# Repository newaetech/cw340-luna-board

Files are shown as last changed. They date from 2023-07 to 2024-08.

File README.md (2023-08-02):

# CW340 Luna Baseboard

This repository contains the hardware documentation for the CW340 Luna Baseboard. This board supports multiple larger FPGA target boards.

### Status

The baseboard is now released. 

Latest (Revision 05) Known Issues:
* A production mod is applied to add a pull on the reset pins. This has been done on all shipped boards.

## CW341 Kintex Ultrascale KU095 Target

### Status

The board is now released.

## CW342 Kintex K410T Target

### Status

Early alpha has been built & tested.

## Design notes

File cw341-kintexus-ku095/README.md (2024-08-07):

# CW341 Luna Board (Kintex UltraScale Daughtercard)

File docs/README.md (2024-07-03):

# CW340 Luna Board (OpenTitan Baseboard)

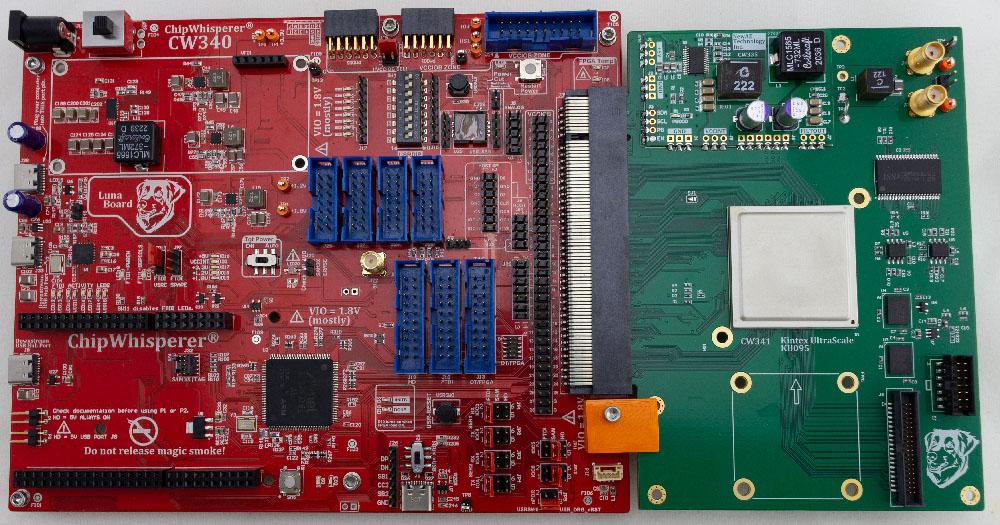
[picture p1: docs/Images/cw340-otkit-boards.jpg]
CW340 OTKIT Luna Board

The ChipWhisperer CW340 "Luna Board" is an advanced evaluation platform for FPGA-based security SoC, RoT, or HSM based designs. It is specifically designed to meet the needs of security evaluation purposes, while having the features you would expect in an easy-to-use FPGA development board.

The CW340 is designed specifically for working with the OpenTitan design, either in FPGA emulation or with a production silicon device.

!!! tip "Quick Reference to Schematics and More"
    For the schematic see [Schematic](#reference-material-schematics) section.
    For FPGA examples see [GITHub Repo](https://github.com/newaetech/cw340-luna-board).
	For PCB source files see [GITHub Repo](https://github.com/newaetech/cw340-luna-board)

This board includes a programmable microcontroller that communicates with the target FPGA, as well as a generic FTDI interface for serial & JTAg interface. The microcontroller is responsible for tasks including:

* Configuring/reconfiguring the FPGA using serial or SelectMAP.
* Monitor the FPGA temperature, controlling fans, shutting down power if entering over-temp situation.
* Adjusting the core voltage.
* Controlling the on-board PLL to set required clock frequency.
* Allowing power cycling of the FPGA target.
* Address/data bus which can be used as 30 computer-controller GPIO pins instead.
* Generic SPI interface.

In addition, the board includes several useful features for development of SoC like devices:

* 1x QSPI sockets - one with 1.8V fixed VCC, one with adjustable VCC.
* Standard JTAG headers that are compatible with most Arm & RISC-V debug probes.
* USB with PHY chip.
* PMOD headers
* Large card-edge connector for the FPGA submodule.

## CW341 Kintex UltraScale (OpenTitan Emulation) FPGA Board

The CW340 "OT KIT" edition includes the CW341 Kintex UltraScale FPGA board. This board has a separate
documentation page. Briefly, features of the CW341 include:

* SRAM and HyperRam for memory expansion.
* Simple PCB design makes it possible to build your own (especially useful if you have stock of the FPGAs).
* JTAG and expansion headers on-board.
* Separate VCC-INT power supply module to further simplify building your own board.

The FPGA board also contains multiple features specific for power analysis & fault injection testing:

* Multi-stage filtering of VCC-INT power supplies to reduce noise.
* On-board inductive "shunt" for power measurements.
* Bridgeable test points for performing other operations with VCC-INT supply.
* SMA connectors for voltage fault injection.
* Cross-flow fans allow access to die for EM probing or EMFI fault injection.
* BGA is mounted with open area to allow removal of heat spreader with minimal risk.

## Usage

### OpenTitan

If you want to use OpenTitan with the CW340, we recommend following their instructions at https://github.com/lowRISC/opentitan/blob/master/doc/getting_started/setup_fpga.md

### Custom BitStreams

If instead you want to build and develop your own bitstreams, you may find it more convenient to
use the ChipWhisperer Python API. Using the board in this way is very similar to using the
CW305 or CW310 boards:

```python
# program bitstream
import chipwhisperer as cw
target = cw.target(None, cw.targets.CW340, bsfile="/path/to/bitstream.bit", force=True)

# Set PLLs
target.pll.pll_enable_set(True)
target.pll.pll_outenable_set(False, 0)
target.pll.pll_outenable_set(True, 1)
target.pll.pll_outenable_set(False, 2)

# run at 10 MHz:
target.pll.pll_outfreq_set(10E6, 1)
```

### UART

The CW340 has two options for using UART: 2 FTDI UART channels, and a custom SAM3X microcontroller
driver with 2 channels. `lsusb` on Linux and Device Manager on Windows can be used to
figure out which serial ports are associated with which. The following image shows the two FTDI
channels on the top and the two SAM3X channels on the bottom:

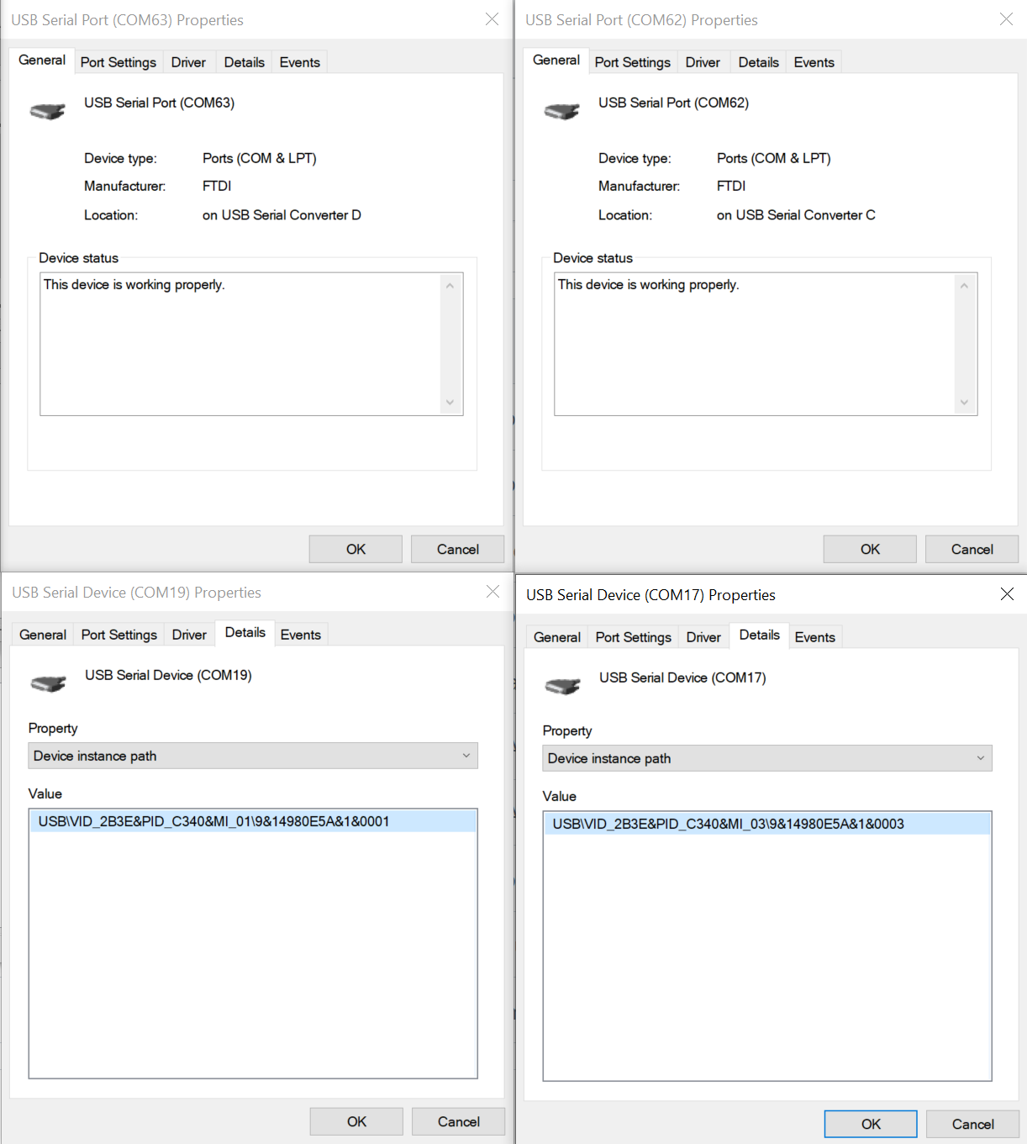
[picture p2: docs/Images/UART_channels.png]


The following is an output from `lsusb -tv`:

```
/:  Bus 03.Port 1: Dev 1, Class=root_hub, Driver=xhci_hcd/4p, 480M
    ID 1d6b:0002 Linux Foundation 2.0 root hub
    |__ Port 2: Dev 2, If 0, Class=Hub, Driver=hub/4p, 480M
        ID 2109:2813 VIA Labs, Inc. VL813 Hub
        |__ Port 2: Dev 4, If 0, Class=Hub, Driver=hub/4p, 480M
            ID 0424:2534 Microchip Technology, Inc. (formerly SMSC) 
            |__ Port 1: Dev 7, If 3, Class=Communications, Driver=cdc_acm, 480M
                ID 2b3e:c340 NewAE Technology Inc. 
            |__ Port 1: Dev 7, If 1, Class=Communications, Driver=cdc_acm, 480M
                ID 2b3e:c340 NewAE Technology Inc. 
            |__ Port 1: Dev 7, If 4, Class=CDC Data, Driver=cdc_acm, 480M
                ID 2b3e:c340 NewAE Technology Inc. 
            |__ Port 1: Dev 7, If 2, Class=CDC Data, Driver=cdc_acm, 480M
                ID 2b3e:c340 NewAE Technology Inc. 
            |__ Port 1: Dev 7, If 0, Class=Vendor Specific Class, Driver=, 480M
                ID 2b3e:c340 NewAE Technology Inc. 
            |__ Port 2: Dev 6, If 3, Class=Vendor Specific Class, Driver=ftdi_sio, 480M
                ID 0403:6011 Future Technology Devices International, Ltd FT4232H Quad HS USB-UART/FIFO IC
            |__ Port 2: Dev 6, If 1, Class=Vendor Specific Class, Driver=ftdi_sio, 480M
                ID 0403:6011 Future Technology Devices International, Ltd FT4232H Quad HS USB-UART/FIFO IC
            |__ Port 2: Dev 6, If 2, Class=Vendor Specific Class, Driver=ftdi_sio, 480M
                ID 0403:6011 Future Technology Devices International, Ltd FT4232H Quad HS USB-UART/FIFO IC
            |__ Port 2: Dev 6, If 0, Class=Vendor Specific Class, Driver=ftdi_sio, 480M
                ID 0403:6011 Future Technology Devices International, Ltd FT4232H Quad HS USB-UART/FIFO IC
```

#### Troubleshooting: /dev/ttyUSB* Not Showing Up

If the FTDI UART channels aren't showing up in Linux (usually `/dev/ttyUSB1-4`), the most likely cause is that the FTDI driver isn't being loaded.

Run the following command to install and load the driver:

```bash
sudo apt install linux-modules-extra-`uname -r` # install driver
sudo modprobe ftdi_sio # load driver
```

By default, this will only load the driver for this boot session, meaning if you restart, you'll need to rerun the `modprobe` command. To load
the FTDI driver on boot, append `ftdi_sio` to `/dev/modules`

### Jumpers

#### UART Jumpers (JP1-JP4)

The default UART IO pins for OpenTitan (OT_IOC3, OT_IOC4, OT_IOA0, and OT_IOA1) can be routed to the following locations:

1. Onboard FTDI UART chip
1. Onboard SAM3X microcontroller
1. Header pins (J18)

For most situations, we recommend routing to the FTDI UART pins.

Note that TX/RX are from the FPGA's perspective, so that things are sent to the FPGA on the RX line and sent from the FPGA on the TX line.

#### Other Jumpers

Most other jumpers on the CW340 will not need to be touched by the user. They do the following:

* JP5 routes the OpenTitan power on reset pin to either a switch (USRSW0) or J29
* JP6 routes 1.8V to User SPI 1
* JP7 has GPIOL0 and GPIOL1 of FTDI channel D
* JP8 has PLL_CLK2 and the /USB_CE signal
* JP9 can be used to set VCCIOB to either 1.2V, 1.8V, or 3.3V
* JP11 and JP12 set OT_IOC5 and OT_IOC8, respectively, to either FTDI control or SAM3X control
* JP13 sets the 1.8V supply for the FTDI chip to either come from the SAM 1.8V regulator, or from a separate regulator 

## Firmware Upgrade

If you need to upgrade the firmware on the SAM3X (control microcontroller), this is currently done through two steps:

1. Erase the SAM3X, causing it to enter bootloader mode.
2. Program the SAM3X with the new firmware.

See the following for details of these steps.

!!! tip "Automatic Bootloader"
    Our other devices have a simplified "automatic" bootloader programmer - currently the CW340 firmware isn't distributed with ChipWhisperer, so for now use the following manual method.

### Step 1: Erasing the SAM3X

This can be done in two ways. Via Python:

```
import chipwhisperer as cw
target = cw.target(None, cw.targets.CW340)
programmer = cw.SAMFWLoader(scope=target)
programmer.enter_bootloader(really_enter=True)
```

Alternative, short the jumper holes marked "ERASE" (J20) with a paperclip, tweezers, etc.

If this part is successful, the leds D23 and D9 will be dimly lit. The CW340 will then **re-enumerate as a serial port**.

### Step 2: Reprogramming the SAM3X

In the following step, you may need to add explicit permission for the bootloader serial port. This is a different USB interface than is normally used by the device.

Get the latest firmware from GIT, note that the file is stored as part of the CW340 repo:

```
wget https://github.com/newaetech/cw310-bergen-board/raw/main/microfw/CW310/src/CW340.bin
```

And then:

```python
import chipwhisperer as cw
programmer = cw.SAMFWLoader(scope=None)
programmer.program('COM3', 'CW340.bin')
```

If this is successful you will see something like:

```
Opening firmware...
Opened!
Connecting...
b'\n\r'
Connected!
Erasing...
Erased!
Programming file CW340.bin...
Programmed!
Verifying...
Verify OK!
Bootloader disabled. Please power cycle device.
```

Press the "USB RST" button (SW5) on the board or power cycle it.

!!! tip "No Touch Bootloader"
    The latest git will support an automatic bootloader which does not require you to power cycle or touch the physical board. If your board automatically re-enumerates, you do not need to do the "USB RST" command.

## Reference Material (Schematics)

* [View schematics online](https://github.com/newaetech/cw340-luna-board/blob/main/docs/NPCA-CW340-LUNABOARD-05.PDF)
* [Download PDF of Schematics](https://github.com/newaetech/cw340-luna-board/raw/main/docs/NPCA-CW340-LUNABOARD-05.PDF)

## Errata

### PLL

PLLs 1 and 2 are swapped from the CW305. The ChipWhisperer Python library swaps them back such that setting
PLL1 sets PLL_CLK1 on the schematic. Third party libraries may or may not perform this swap.

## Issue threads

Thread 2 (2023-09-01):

Notebook tests: XADC failure (plus jumper J23/24 warning)

jwnrt, 2023-09-01:
Hi, great work on the CW340 :)

I've just run through the notebook tests with a 340 in its out-of-the-box configuration.

All the tests have passed fine, except the final XADC check hits this assertion:

```
---------------------------------------------------------------------------
AssertionError                            Traceback (most recent call last)
Cell In[27], line 1
----> 1 assert target.xadc_status == 'good'
      2 assert target.temp < 60 # somewhat arbitrary

AssertionError:
```

Is this expected / acceptable? Is there something I need to configure differently here?

Additionally, the notebook prints this warning at the `target.fpga_buildtime` step but J23 and J24 are definitely connected with the jumper cable:

```
(ChipWhisperer Target WARNING|File CW340.py:95)
                    Reading/writing the FPGA with this class requires a jumper cable from:
                    - the third bottom left pin of the blue J24 header (pin 9, USB_SPI_CS on the schematic)
                    to:
                    - the third bottom left pin of the blue J23 header (pin 9, OT_SPI_DEV_CS_L on the schematic)
                    You can also simply connect a ribbon cable between J23 and J24.
                    This warning is printed once as a reminder; set target.jumper_warned to True to
                    avoid seeing it.
```

Thanks!

colinoflynn, 2023-09-01:
The notebook was more internal testing so wasn't documented yet ;-) The jumper cable thing you can ignore for sure, that was an artifact of our test setup (where the boards didn't have a cable, and originally we needed a jumper as were doing a different test which didn't use the cable wiring).

I'll have to check with @jpcrypt on the XADC status note. What does the `xadc_status` show?

jwnrt, 2023-09-01:
I've just tried that test again and can't reproduce the XADC assertion any more (I believe it was hitting every time previously).

I haven't changed any board configuration, so maybe just power cycling made it go away.

Thanks for confirming the jumper cable warning can be ignored

jwnrt, 2023-09-01:
> if you see HyperRam issues that isn't a problem

Great, thanks

The HyperRam test runs I've done so fare have all been ~99.5% pass rate which is presumably within okay bounds?

jwnrt, 2023-09-01:
```
print(target)

fpga_buildtime  = 8/22/2023, 20:34
xadc_status     = VCCint alarm, VCCbram alarm,
max_temp        = 37.03578491210942
temp            = 35.55929565429693
max_vccint      = 0.930908203125
max_vccbram     = 0.930908203125
max_vccaux      = 1.795166015625
current_vccint  = 0.926513671875
current_vccbram = 0.92724609375
current_vccaux  = 1.7900390625
vaux0           = 0.0
vaux1           = 0.0
vaux8           = 0.0
vaux12          = 0.0
```

jpcrypt, 2023-09-01:
The alarm limits on VCC are from the ultrascale recommended operating conditions, so 0.922 - 0.979 for vccint and vccbram. We don't report the minimums but we can infer from your numbers that the minimum must have gone below 0.922.
What is your VCCint set to? `target.vccint_get()`.
You can set it to e.g. `target.vccint_set(0.95)`, then set `target.xadc_status = 0` to clear the alarms.

jwnrt, 2023-09-01:
> What is your VCCint set to? `target.vccint_get()`.

```
target.vccint_get()
> 1.0
```

> You can set it to e.g. `target.vccint_set(0.95)`, then set `target.xadc_status = 0` to clear the alarms.

Thank you, will do

colinoflynn, 2023-09-05:
One note on VCCINT just to keep it in this issue (in case we search for it in the future) -

The VCCINT "set" is the output of the power supply itself. On the CW341 there is some additional filtering along with an inductive "shunt". In practice this adds some voltage drop. We may eventually need to adjust up the default voltage in order to get VCCINT in range, as there is some additional voltage drop beyond just the PCB traces resulting from that filtering/shunt.

This is present as the board has dual-usage, they can be quickly modified to perform power analysis for testing the crypto accelerators for side-channel leakage. The boards as-shipped tried to minimize the impact (they do have decoupling caps so you should have a stable design), but we did leave the shunt in there since it's something that will be more annoying for end users to change if they needed to.

Closed 2023-09-03.

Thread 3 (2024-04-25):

New CW340 board is non-functional

AndySecqai, 2024-04-25:
We have fresh-out-of-the-box CW340 card that appears to be non-functional and require some assistance with debugging.

Once connected to the host computer, we can successfully run the OpenTitan [set-pll](https://opentitan.org/book/doc/getting_started/setup_fpga.html#detecting-the-board) command, which I think indicates that USB communications are working to the SAM3X, and I2C communications are working from the SAM3X to the PLL.

`dmesg -Hw` is not showing any errors, and `lsusb` appears to be detecting things as I would expect:
```
Bus 003 Device 004: ID 0403:6011 Future Technology Devices International, Ltd FT4232H Quad HS USB-UART/FIFO IC
Bus 003 Device 005: ID 2b3e:c340 NewAE Technology Inc. ChipWhisperer CW340 - Luna Board
Bus 003 Device 002: ID 0424:2534 Microchip Technology, Inc. (formerly SMSC)
```

However, from this point, nothing seems to be able to communicate correctly:
- the Vivado Hardware Manager reports that there are no connected devices
- the opentitantool (when set to [program the bitstream](https://opentitan.org/book/doc/getting_started/setup_fpga.html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)) returns `Error: Transport does not support Uart` (which I think means it can't detect the right JTAG connection?)
- trying to update the SAM3X firmware following [this](https://rtfm.newae.com/Targets/CW340%20Luna%20Board/#step-1-erasing-the-sam3x) guide also fails with the following:
```
target = cw.target(None, cw.targets.CW310)
Traceback (most recent call last):
  File "<stdin>", line 1, in <module>
  File "<removed>/python3.10/site-packages/chipwhisperer/__init__.py", line 7, in target
    rtn.con(scope, **kwargs)
  File <removed>/python3.10/site-packages/chipwhisperer/capture/targets/_base.py", line 65, in con
    self._con(scope, **kwargs)
  File <removed>/python3.10/site-packages/chipwhisperer/capture/targets/CW310.py", line 122, in _con
    self._naeusb.con(idProduct=[0xC310], serial_number=sn, hw_location=hw_location)
  File "<removed>/python3.10/site-packages/chipwhisperer/hardware/naeusb/naeusb.py", line 681, in con
    self.usbtx.open(idProduct=idProduct, serial_number=serial_number, connect_to_first=True, hw_location=hw_location)
  File "<removed>/python3.10/site-packages/chipwhisperer/hardware/naeusb/naeusb.py", line 371, in open
    self.device = self.find(serial_number, idProduct, hw_location=hw_location)
  File "<removed>/python3.10/site-packages/chipwhisperer/hardware/naeusb/naeusb.py", line 338, in find
    raise OSError("Could not find ChipWhisperer. Is it connected?")
OSError: Could not find ChipWhisperer. Is it connected?
```

At this point, it looks to me like there is something wrong with the FTDI-to-FPGA connection, and/or the FPGA itself is dead (particularly due to the Vivado Hardware Manager not being able to see it), but hopefully someone has an idea of some other tests to try before I RMA it back to the distributer...

Thanks,
Andy

jpcrypt, 2024-04-25:
How are you powering the board, what are the positions of all the power delivery switches, and what LEDs are on or blinking?

AndySecqai, 2024-04-25:
Please see attached for a picture of the board configuration with the various leds showing:
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

We are mostly following the OpenTitan getting started guide [here](https://opentitan.org/book/doc/getting_started/setup_fpga.html#cw340-board), however we have SW7 to the left as the board seems unpowered with it to the right as stated in that guide.

If it is possible to tell from the attached pictures, do our jumpers look correctly configured? They've been left as-was from taking it out of the box...

AndySecqai, 2024-04-25:
Hi @colinoflynn - I just took a quick look at the test note book you linked to, but it seems like maybe something isn't right in my python environment:
```
<user>:~/cw340-luna-board/fpga/vivado/cw341.runs/impl_1$ python3
Python 3.10.12 (main, Nov 20 2023, 15:14:05) [GCC 11.4.0] on linux
Type "help", "copyright", "credits" or "license" for more information.
>>> import chipwhisperer as cw
>>> bsfile = 'cw341_top.bit'
>>> target = cw.target(None, cw.targets.CW340, bsfile=bsfile, force=True)
Traceback (most recent call last):
  File "<stdin>", line 1, in <module>
AttributeError: module 'chipwhisperer.capture.targets.CW310' has no attribute 'CW340'. Did you mean: 'CW310'?
```

jpcrypt, 2024-04-25:
Can you update your ChipWhisperer installation to the develop branch?
It should then work.
Then you can try the test notebook [here](https://github.com/newaetech/cw340-luna-board/blob/main/jupyter/CW340_test.ipynb) to do basic validation.
You should see blinking blue and red LEDs to indicate that clocks are alive. A single additional jumper is required to run the tests, as explained in the notebook.

AndySecqai, 2024-04-26:
@jpcrypt sorry - probably a dumb question on my part, but I'm not much of a python user - how would I change the installation to the develop branch? I just installed it with `pip3 install chipwhisperer`

AndySecqai, 2024-04-26:
Sorry - ignore the above, I found the install instructions in the chipwhisperer repo. I'm pretty sure I got the the `develop` branch set up correctly, but the Python instructions still don't seem right:

```
:~/cw340-luna-board/fpga/vivado/cw341.runs/impl_1$ python
3
Python 3.10.12 (main, Nov 20 2023, 15:14:05) [GCC 11.4.0] on linux
Type "help", "copyright", "credits" or "license" for more information.
>>> import chipwhisperer as cw
>>> bsfile='cw341_top.bit'
>>> target = cw.target(None, cw.targets.CW340, bsfile=bsfile, force=True)
Traceback (most recent call last):
  File "<stdin>", line 1, in <module>
AttributeError: module 'chipwhisperer' has no attribute 'target'
>>>
```

Closed 2024-04-29.

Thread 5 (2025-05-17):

How to use DEV SPI.

fetch150zy, 2025-05-17:
Hi, I have some doubts about the use of CW340's DEV SPI. I couldn't find a clear DEV SPI marking on the board, I only found the pins for HOST SPI. I want to know how to connect CW340 as a slave device to another development board via SPI.

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

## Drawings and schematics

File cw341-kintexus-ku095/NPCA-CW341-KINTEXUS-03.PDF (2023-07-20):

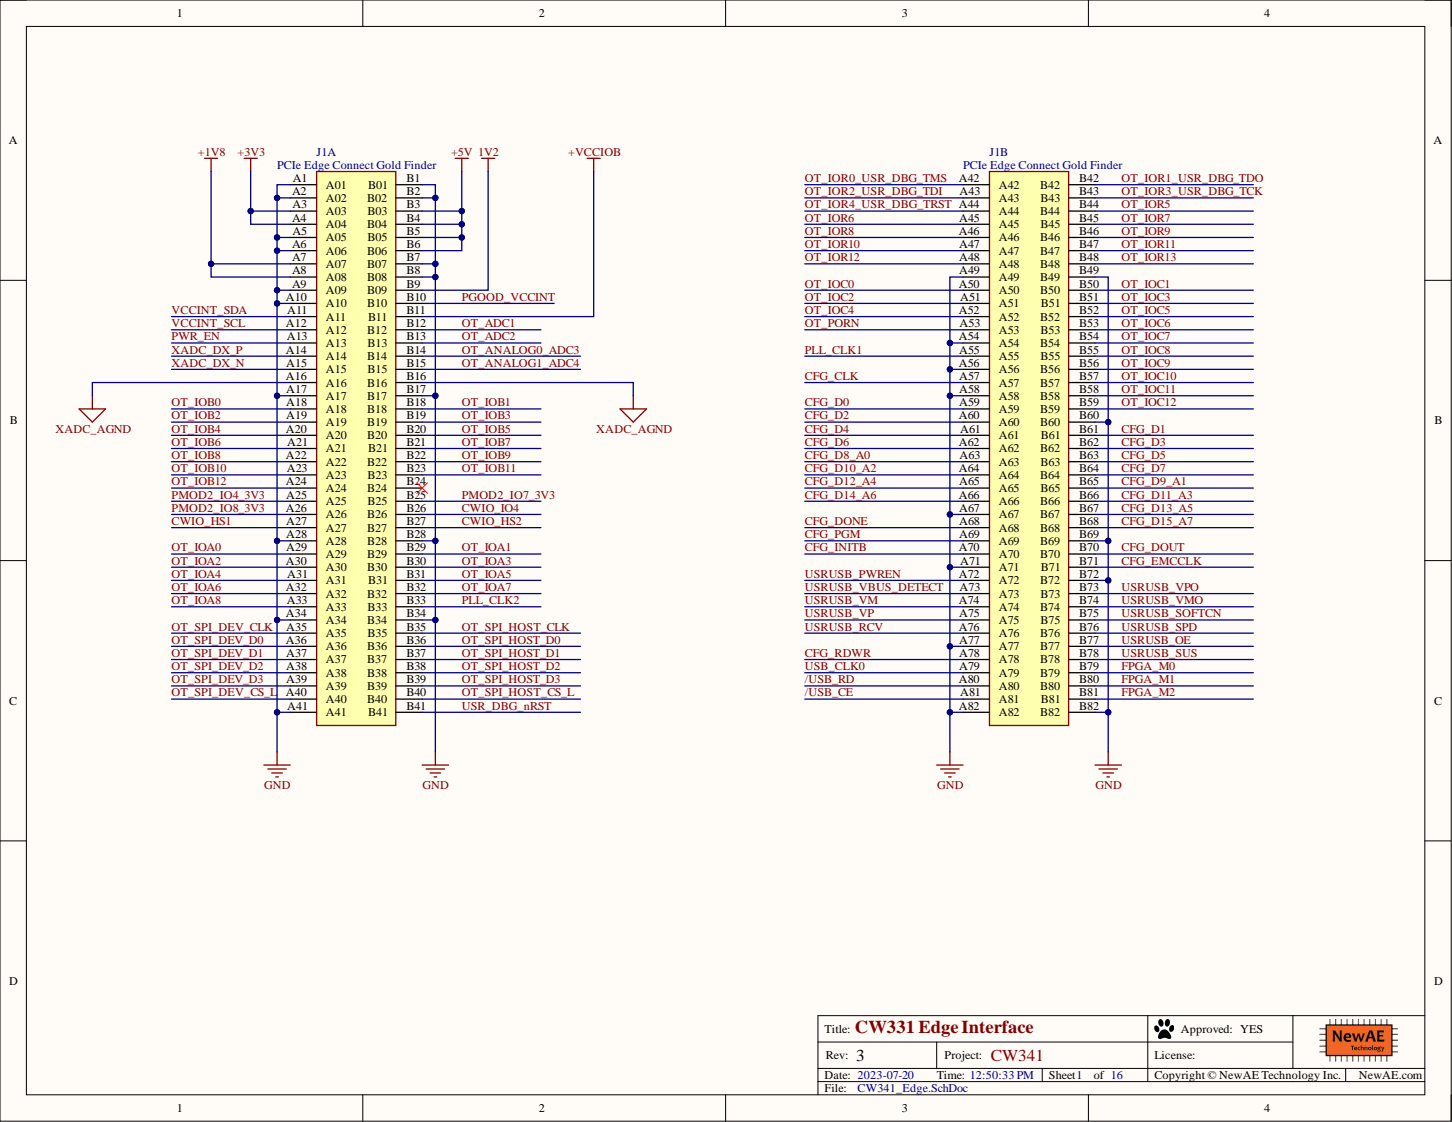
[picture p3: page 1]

PCIe Edge Connect Gold Finder

A02 A2
A03 A3
A04 A4
A05 A5
A06 A6

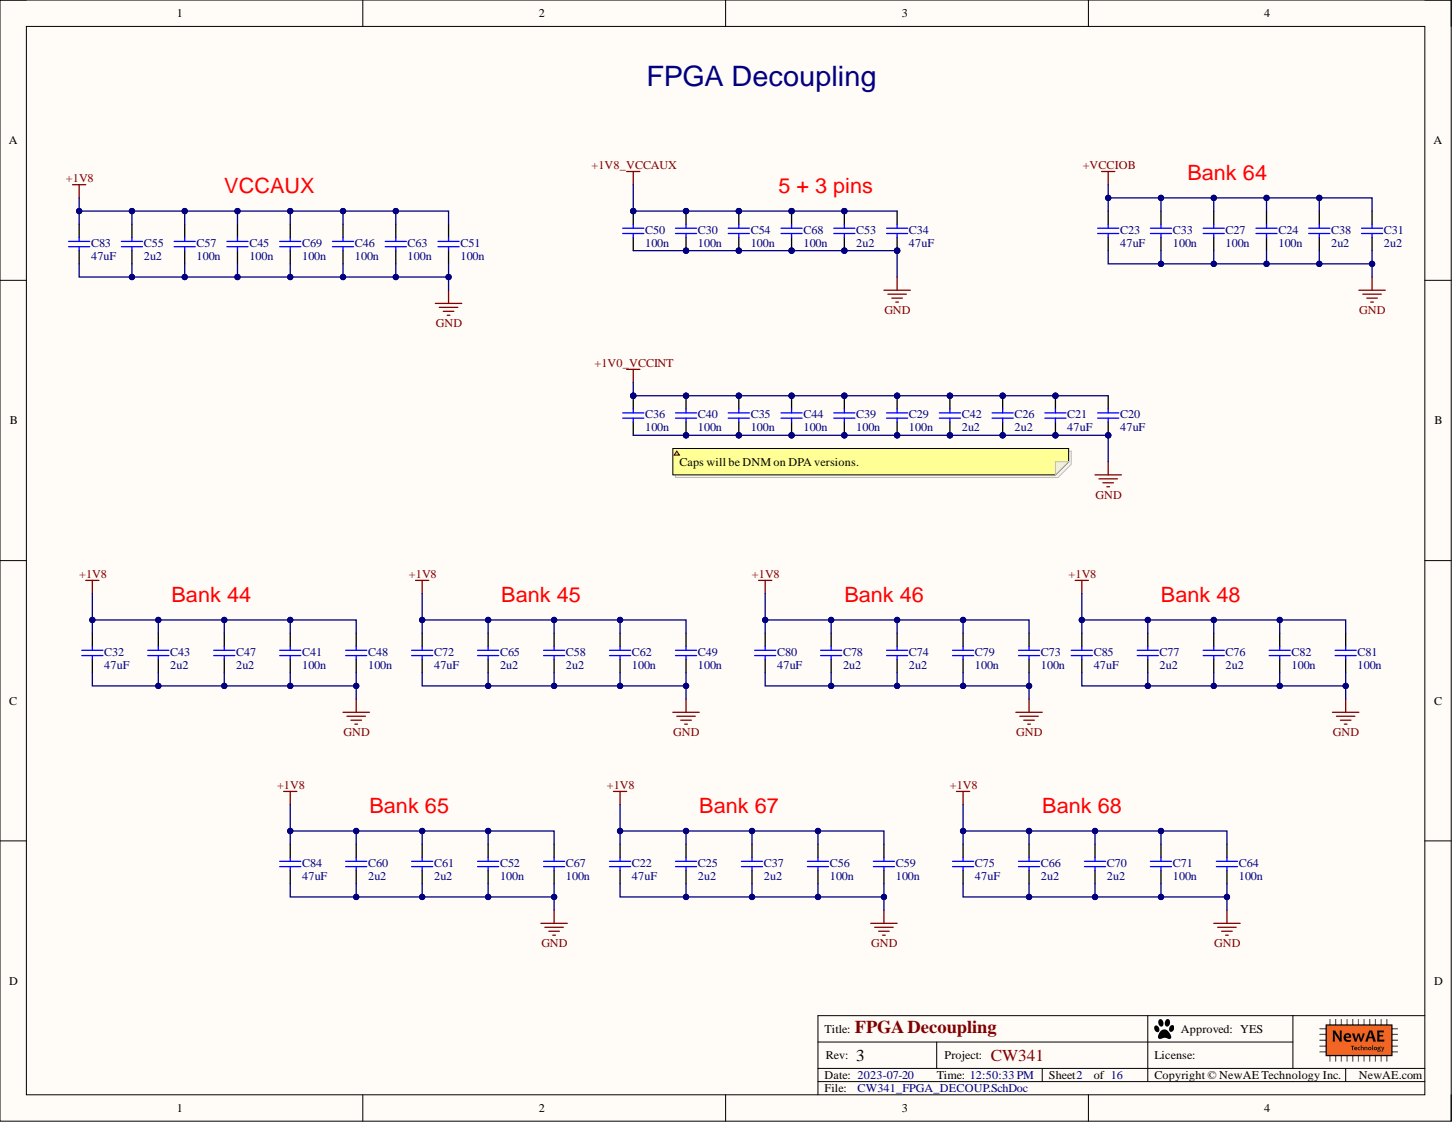
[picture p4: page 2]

Caps will be DNM on DPA versions.

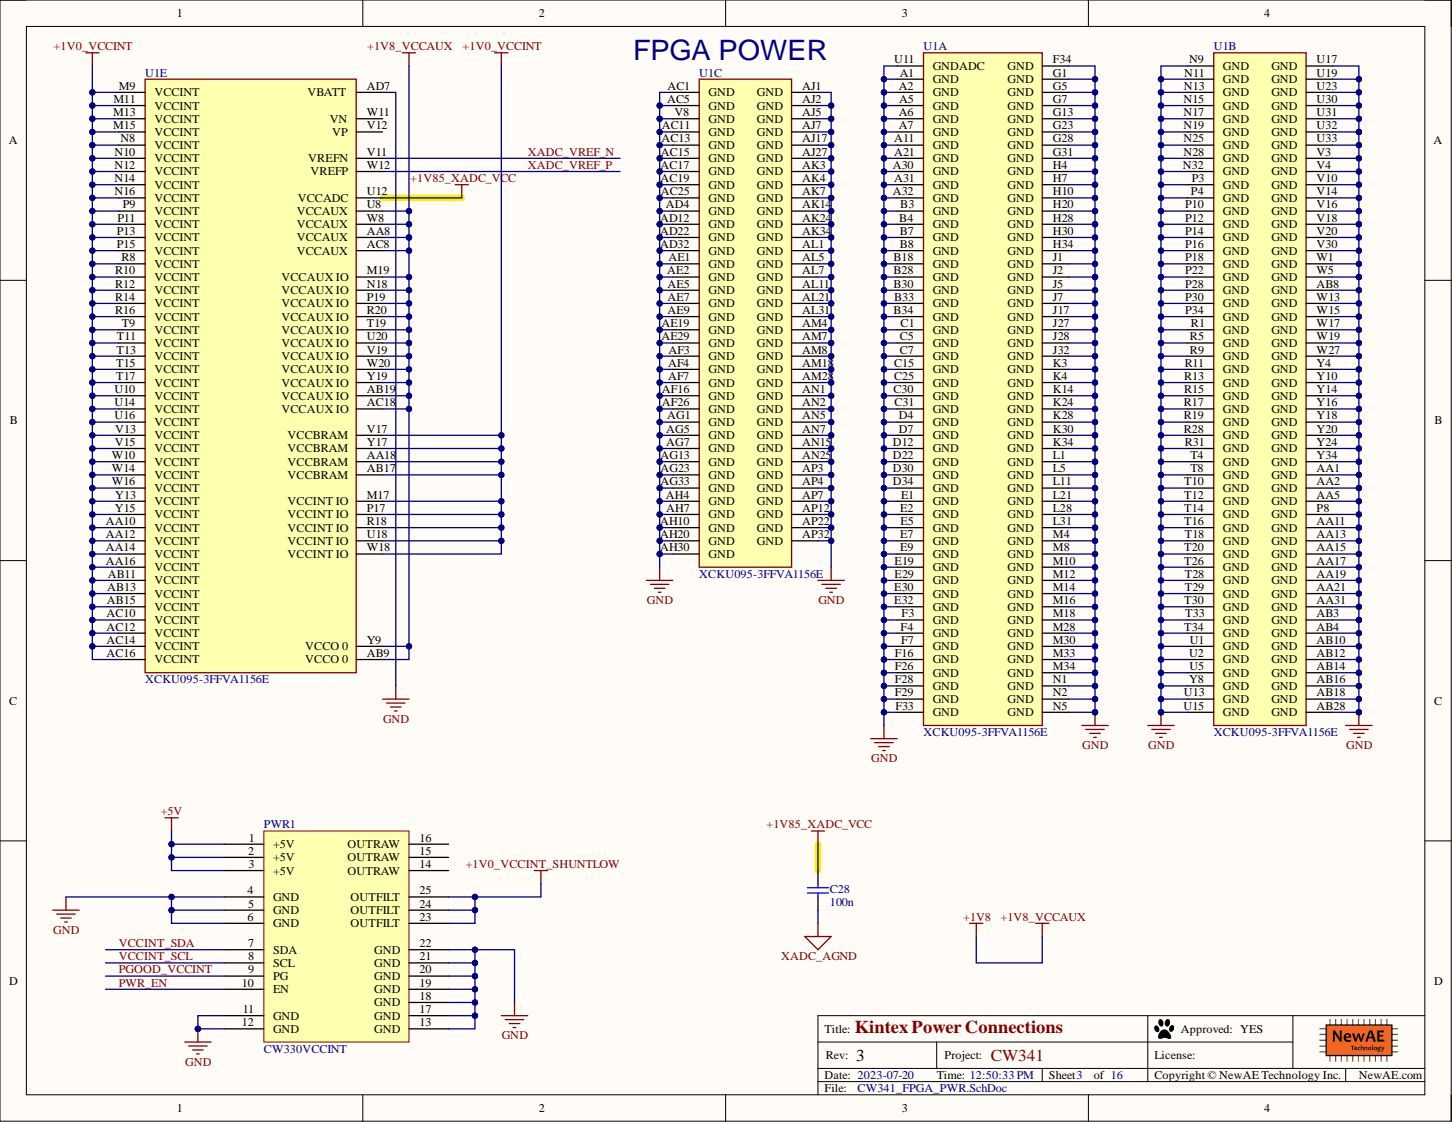
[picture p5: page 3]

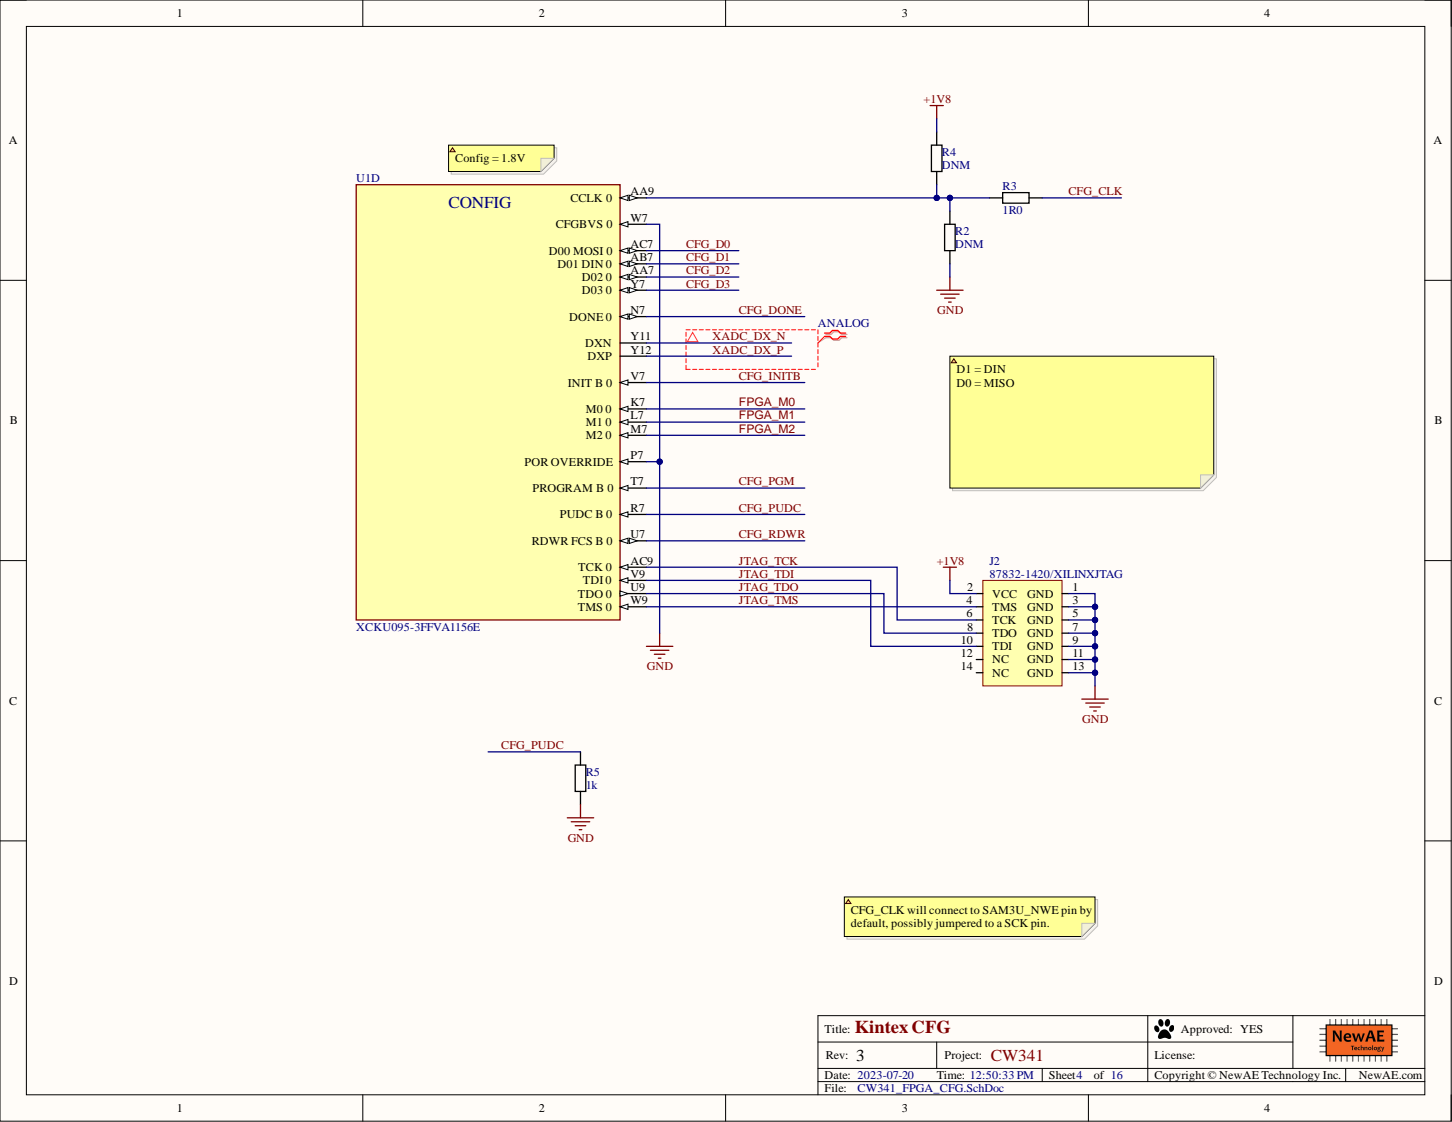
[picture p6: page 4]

JTAG_TDI
JTAG_TDO | NC 12 NC 14
JTAG_TMS

CFG_CLK will connect to SAM3U_NWE pin by
default, possibly jumpered to a SCK pin.

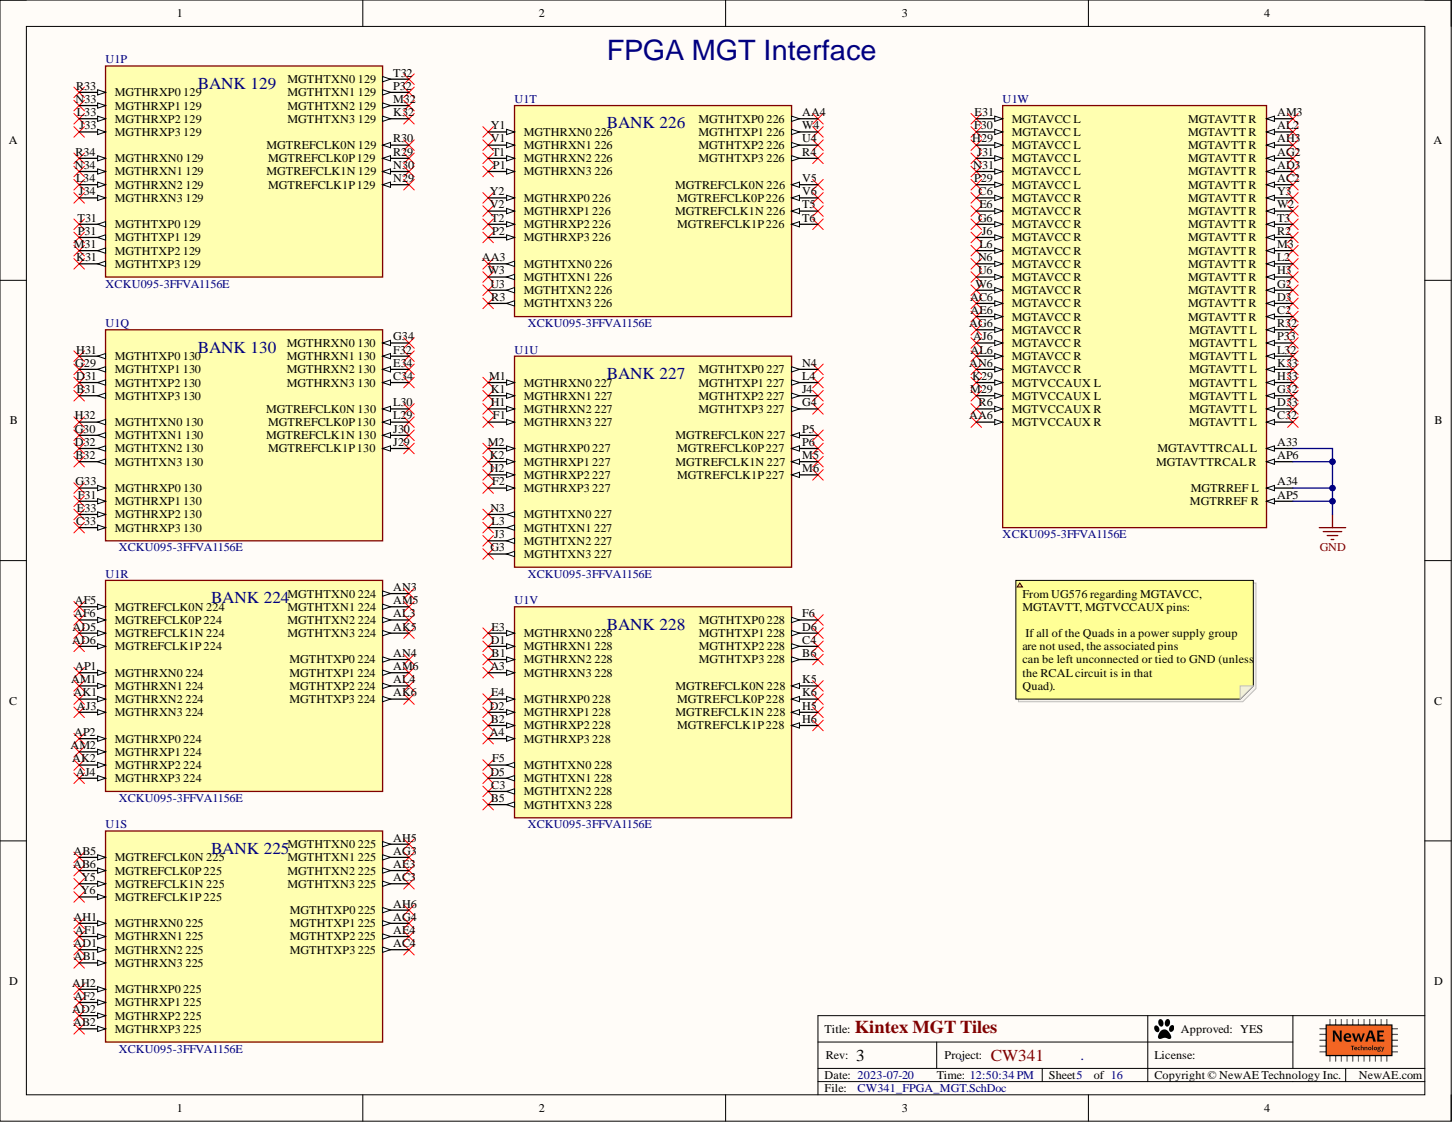
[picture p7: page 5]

If all of the Quads in a power supply group
are not used, the associated pins
can be left unconnected or tied to GND (unless
the RCAL circuit is in that
Quad).

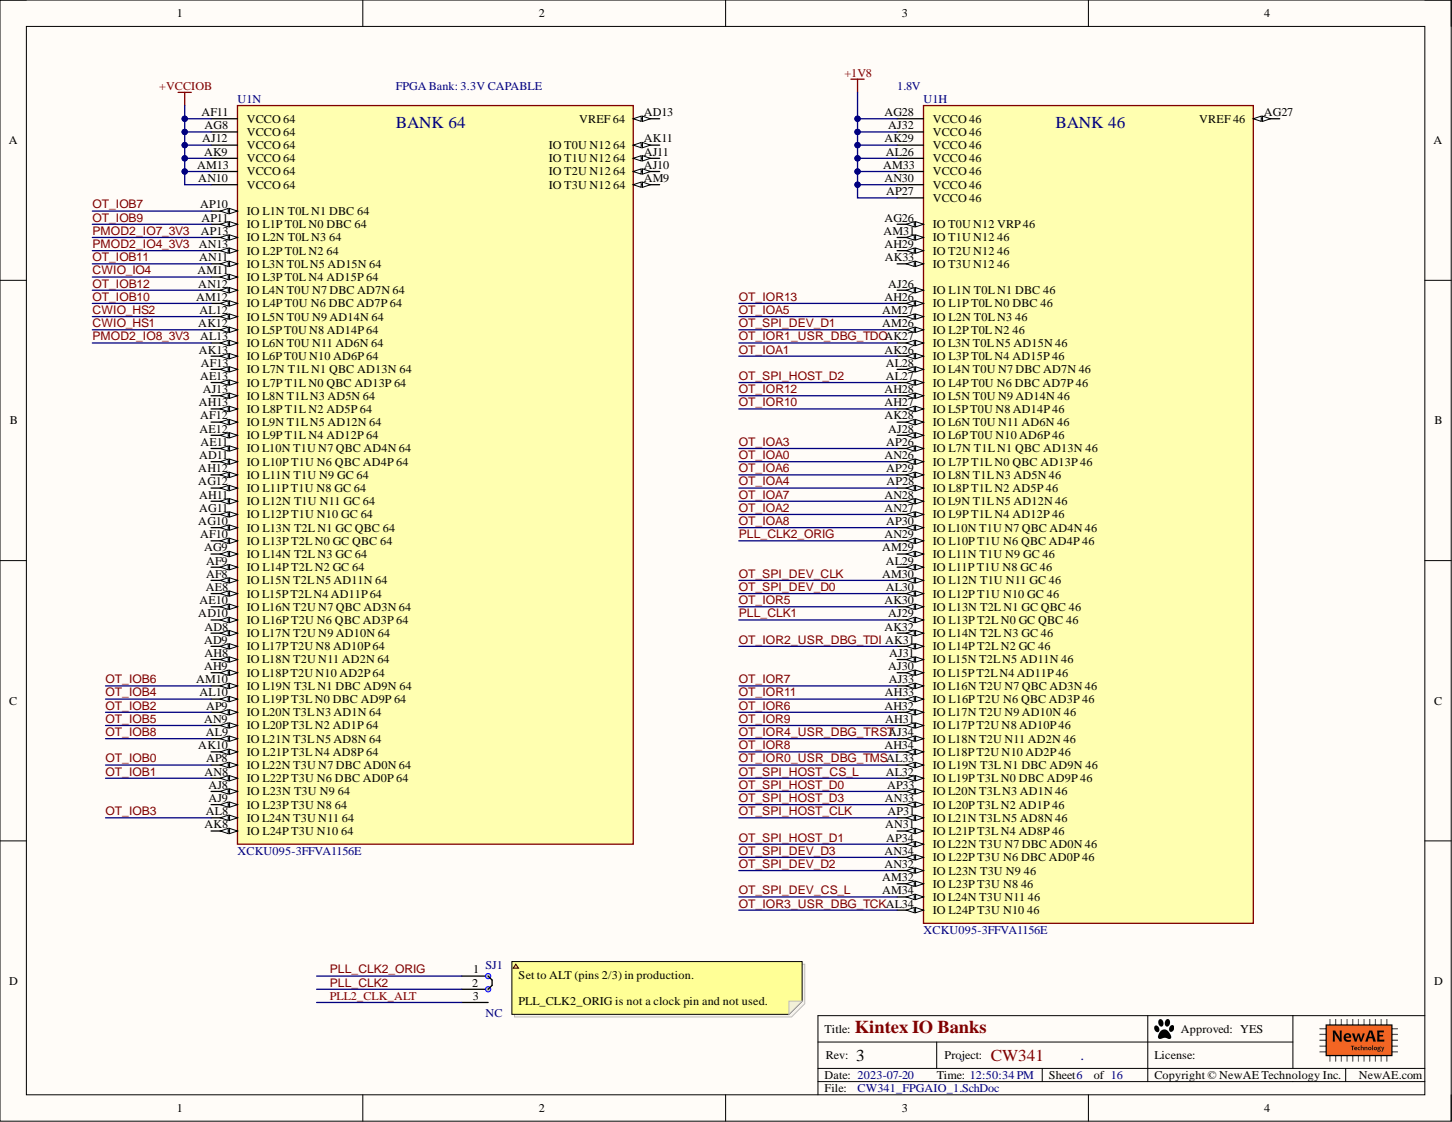
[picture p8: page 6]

Set to ALT (pins 2/3) in production.

PLL_CLK2_ORIG is not a clock pin and not used.

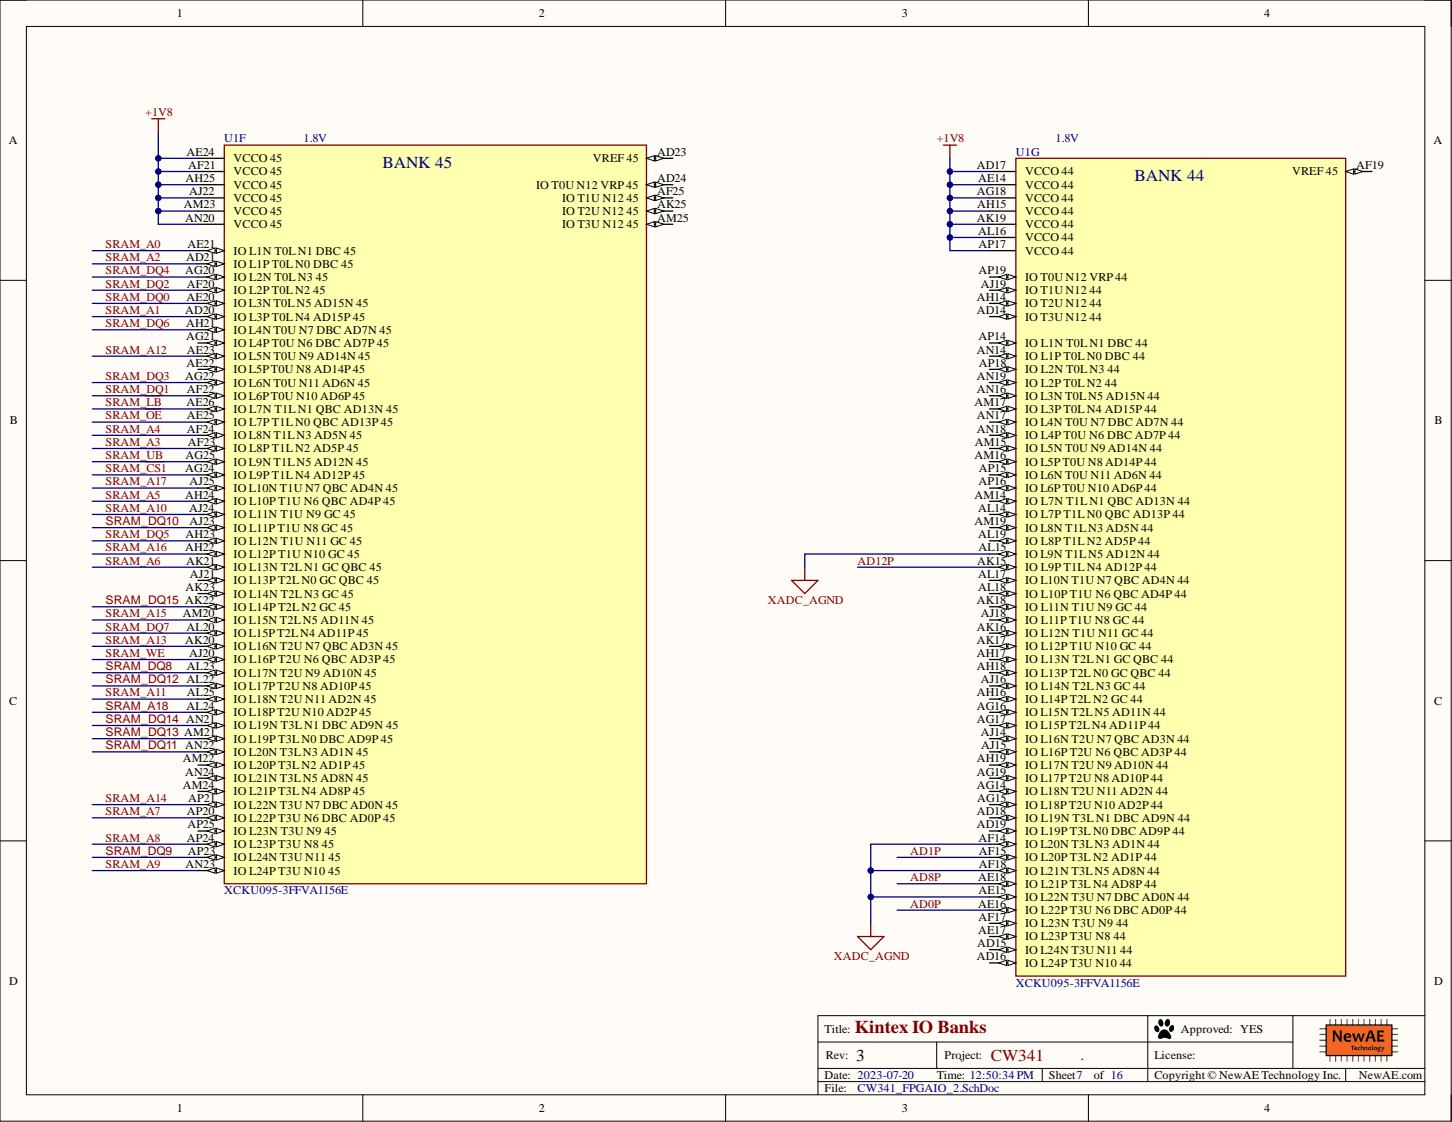
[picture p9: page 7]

AD8P | IO L21P T3L N4 AD8P 44 AE18 IO L22N T3U N7 DBC AD0N 44 AE15

AD0P | IO L22P T3U N6 DBC AD0P 44 AE16 IO L23N T3U N9 44 AF17

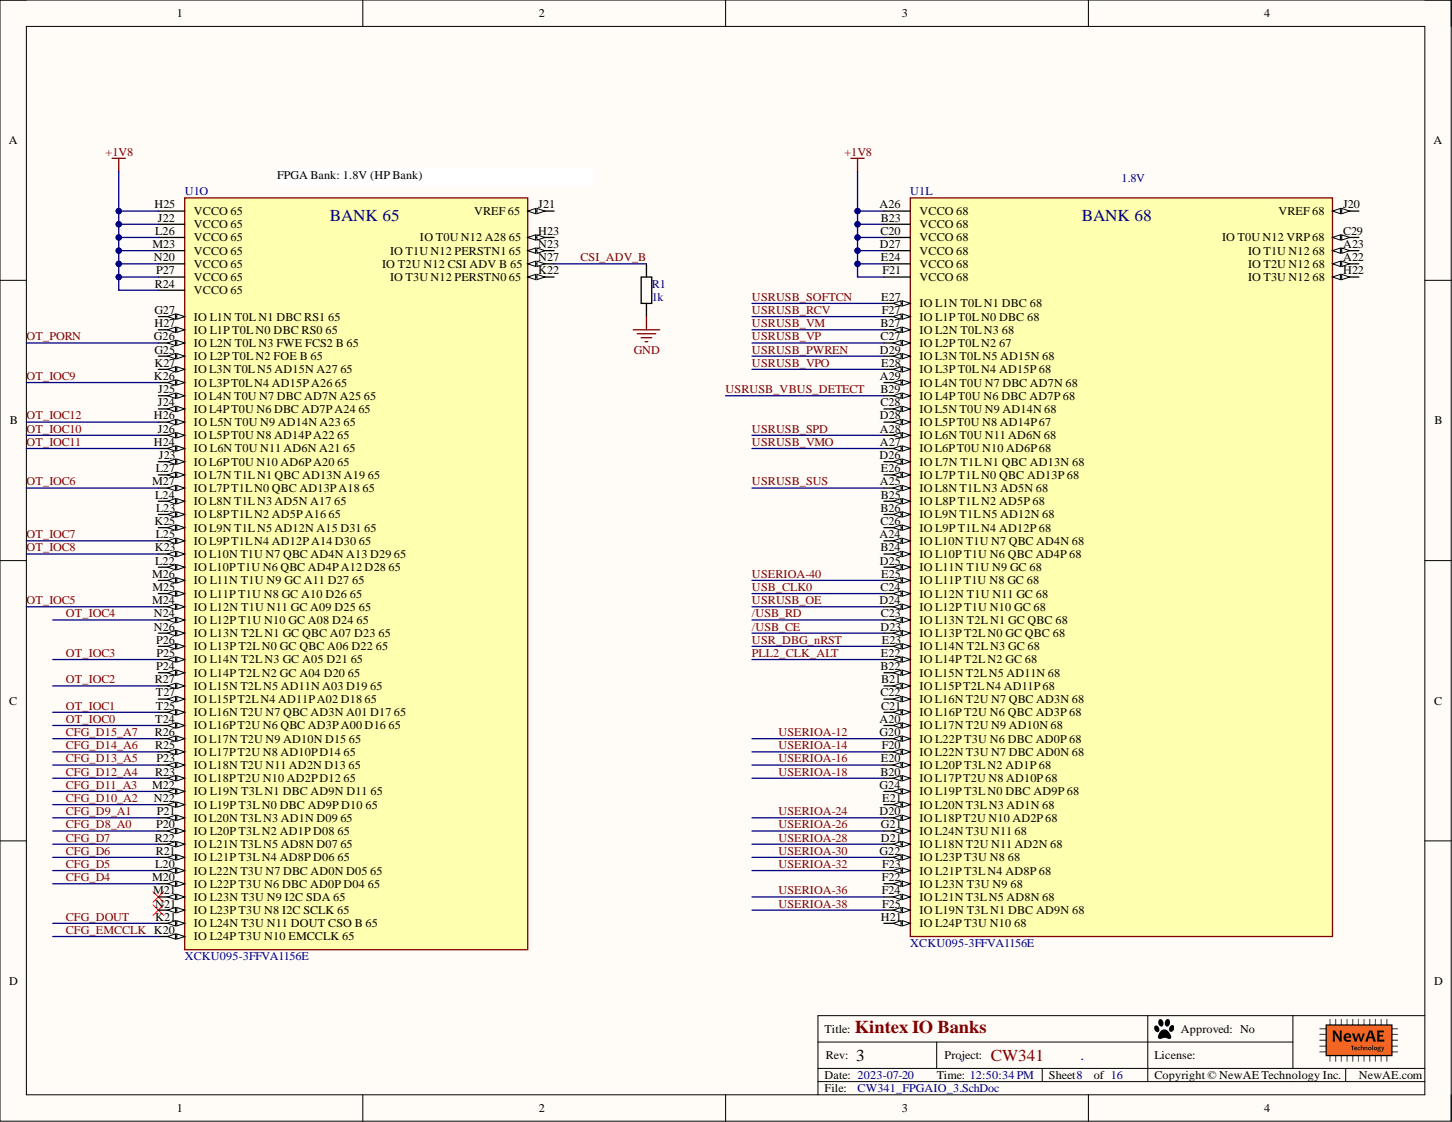
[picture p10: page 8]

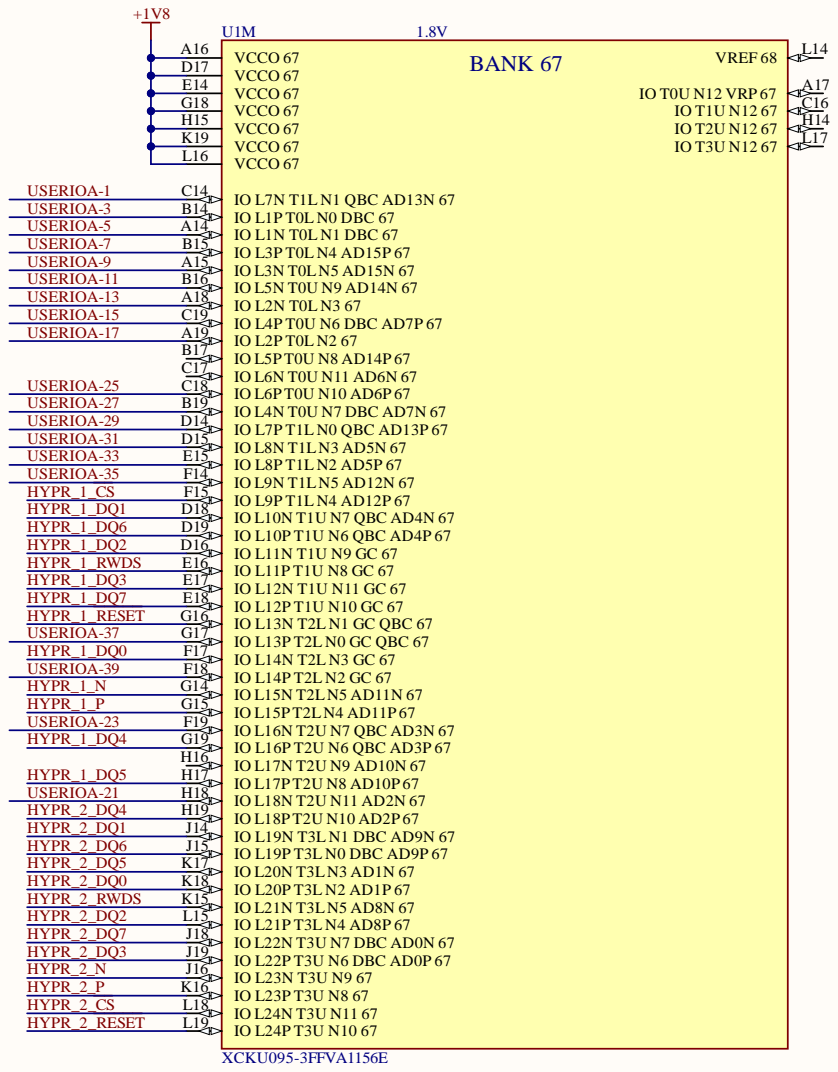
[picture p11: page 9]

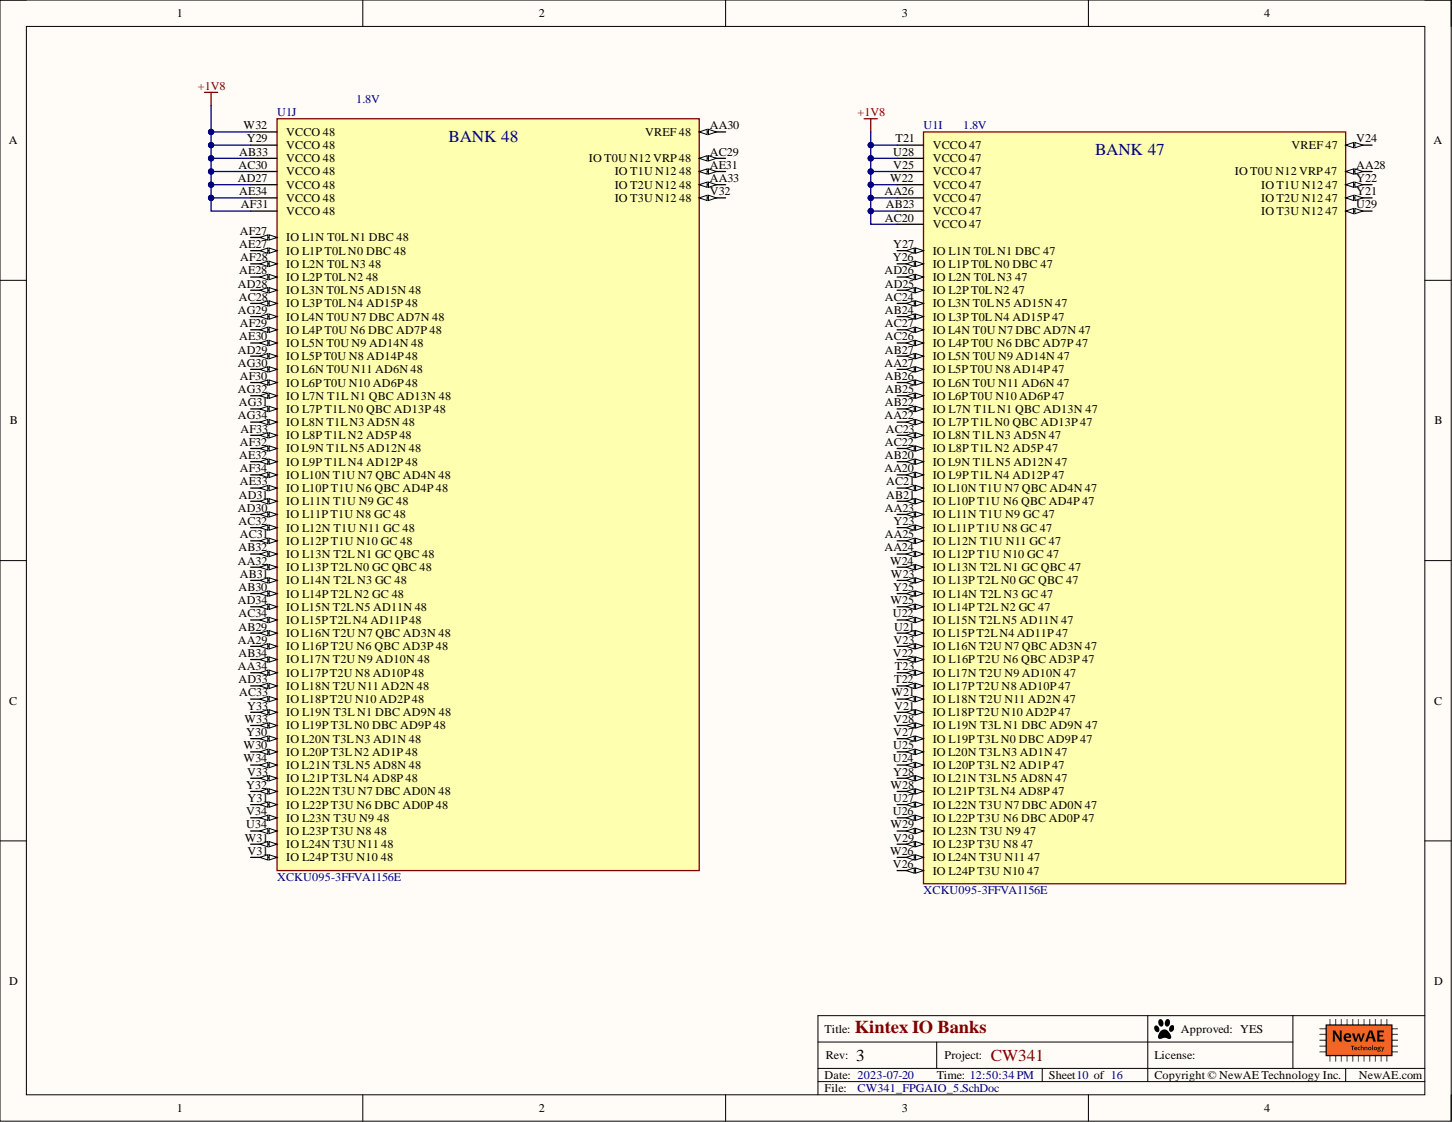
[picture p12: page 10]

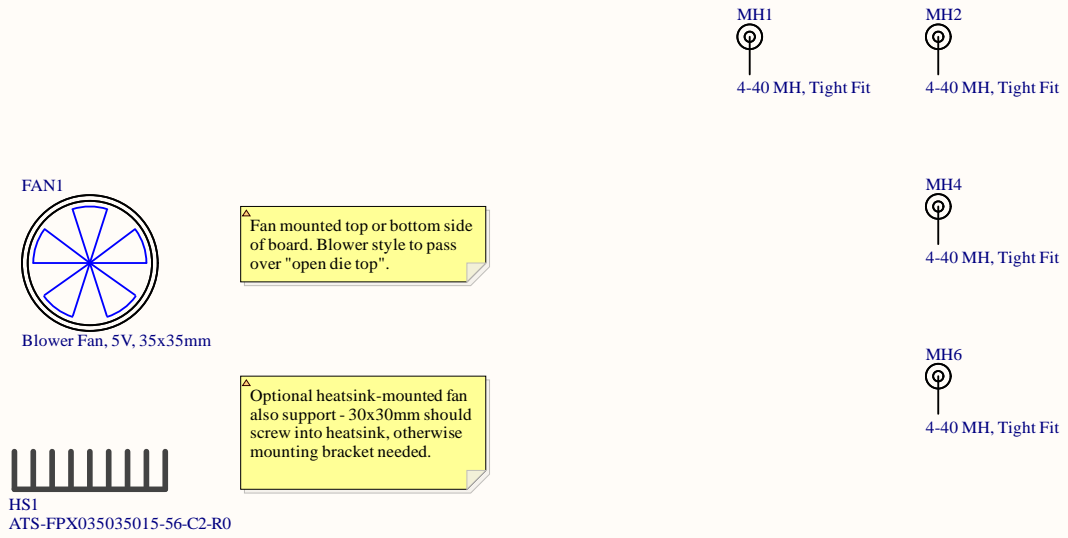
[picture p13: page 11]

Fan mounted top or bottom side
of board. Blower style to pass
over "open die top".

Optional heatsink-mounted fan
also support - 30x30mm should
screw into heatsink, otherwise
mounting bracket needed.

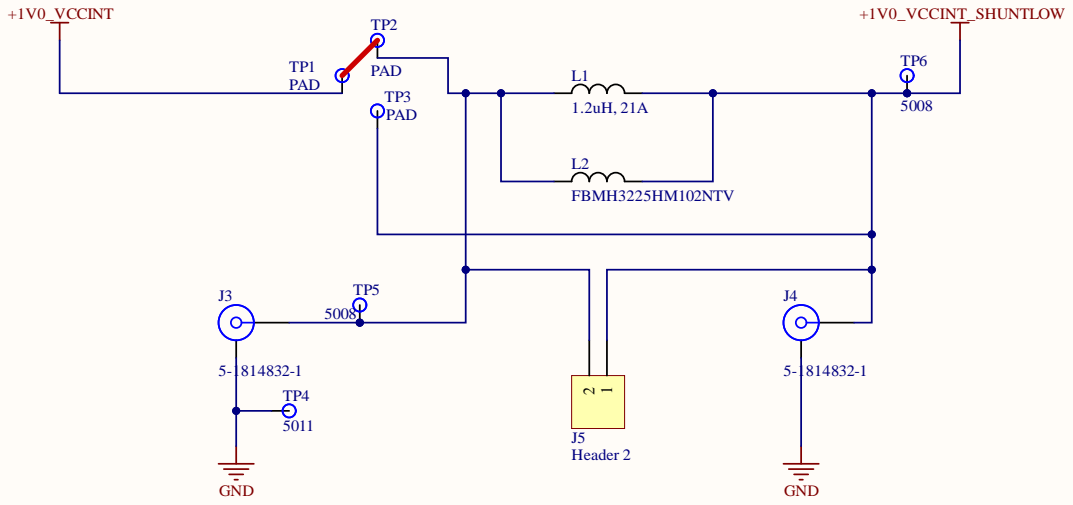
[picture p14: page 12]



These two net names don't look right..
outputs shared with other op amp?

Oops! Yes they should go to another
XADC input positive channel.


See AN211622 for Length Matching Rules and PCB design
considerations


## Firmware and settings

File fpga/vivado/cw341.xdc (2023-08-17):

# default unless otherwise specified:
set_property IOSTANDARD LVCMOS18 [get_ports *]

set_property -dict { PACKAGE_PIN C24   IOSTANDARD LVCMOS18 } [get_ports { usb_clk }]; # labeled /USB_RD on schematic

set_property -dict { PACKAGE_PIN AM34  IOSTANDARD   LVCMOS18 } [get_ports { USB_ALEn }];  # NOTE: using USB_SPI_CS; needs jumper between J23 and J24
set_property -dict { PACKAGE_PIN  C23  IOSTANDARD   LVCMOS18 } [get_ports { USB_nRD   }]; # labeled /USB_RD on schematic
set_property -dict { PACKAGE_PIN  D23  IOSTANDARD   LVCMOS18 } [get_ports { USB_nCE   }]; # labeled /USB_CE on schematic

set_property -dict { PACKAGE_PIN  P20  IOSTANDARD   LVCMOS18 } [get_ports { USB_AD[0]  }];
set_property -dict { PACKAGE_PIN  P21  IOSTANDARD   LVCMOS18 } [get_ports { USB_AD[1]  }];
set_property -dict { PACKAGE_PIN  N22  IOSTANDARD   LVCMOS18 } [get_ports { USB_AD[2]  }];
set_property -dict { PACKAGE_PIN  M22  IOSTANDARD   LVCMOS18 } [get_ports { USB_AD[3]  }];
set_property -dict { PACKAGE_PIN  R23  IOSTANDARD   LVCMOS18 } [get_ports { USB_AD[4]  }];
set_property -dict { PACKAGE_PIN  P23  IOSTANDARD   LVCMOS18 } [get_ports { USB_AD[5]  }];
set_property -dict { PACKAGE_PIN  R25  IOSTANDARD   LVCMOS18 } [get_ports { USB_AD[6]  }];
set_property -dict { PACKAGE_PIN  R26  IOSTANDARD   LVCMOS18 } [get_ports { USB_AD[7]  }];

#$set_property -dict { PACKAGE_PIN  M20  IOSTANDARD   LVCMOS18 } [get_ports { USB_D[4]  }];
#$set_property -dict { PACKAGE_PIN  L20  IOSTANDARD   LVCMOS18 } [get_ports { USB_D[5]  }];
#$set_property -dict { PACKAGE_PIN  R21  IOSTANDARD   LVCMOS18 } [get_ports { USB_D[6]  }];
#$set_property -dict { PACKAGE_PIN  R22  IOSTANDARD   LVCMOS18 } [get_ports { USB_D[7]  }];

set_property -dict { PACKAGE_PIN AH32  IOSTANDARD   LVCMOS18 } [get_ports { USRLED[0] }]; # OT_IOR6
set_property -dict { PACKAGE_PIN AJ33  IOSTANDARD   LVCMOS18 } [get_ports { USRLED[1] }]; # OT_IOR7
set_property -dict { PACKAGE_PIN AH34  IOSTANDARD   LVCMOS18 } [get_ports { USRLED[2] }]; # OT_IOR8
set_property -dict { PACKAGE_PIN AH31  IOSTANDARD   LVCMOS18 } [get_ports { USRLED[3] }]; # OT_IOR9
set_property -dict { PACKAGE_PIN AH27  IOSTANDARD   LVCMOS18 } [get_ports { USRLED[4] }]; # OT_IOR10
set_property -dict { PACKAGE_PIN AH33  IOSTANDARD   LVCMOS18 } [get_ports { USRLED[5] }]; # OT_IOR11
set_property -dict { PACKAGE_PIN AH28  IOSTANDARD   LVCMOS18 } [get_ports { USRLED[6] }]; # OT_IOR12
set_property -dict { PACKAGE_PIN AH26  IOSTANDARD   LVCMOS18 } [get_ports { USRLED[7] }]; # OT_IOR13


set_property -dict { PACKAGE_PIN AM10  IOSTANDARD   LVCMOS18 } [get_ports { USRDIP[0] }]; # OT_IOB6 NB: USRDIP[0:6] are in bank 64 with CW 20-pin signals and must be set to the same voltage as those
set_property -dict { PACKAGE_PIN AP10  IOSTANDARD   LVCMOS18 } [get_ports { USRDIP[1] }]; # OT_IOB7
set_property -dict { PACKAGE_PIN AL9   IOSTANDARD   LVCMOS18 } [get_ports { USRDIP[2] }]; # OT_IOB8
set_property -dict { PACKAGE_PIN AP11  IOSTANDARD   LVCMOS18 } [get_ports { USRDIP[3] }]; # OT_IOB9
set_property -dict { PACKAGE_PIN AM12  IOSTANDARD   LVCMOS18 } [get_ports { USRDIP[4] }]; # OT_IOB10
set_property -dict { PACKAGE_PIN AN11  IOSTANDARD   LVCMOS18 } [get_ports { USRDIP[5] }]; # OT_IOB11
set_property -dict { PACKAGE_PIN AN12  IOSTANDARD   LVCMOS18 } [get_ports { USRDIP[6] }]; # OT_IOB12
set_property -dict { PACKAGE_PIN AK30  IOSTANDARD   LVCMOS18 } [get_ports { USRDIP[7] }]; # OT_IOR5 NB: cannot be 3.3V


set_property -dict { PACKAGE_PIN AC31  IOSTANDARD   LVCMOS18 } [get_ports { OT_PORN }];
set_property -dict { PACKAGE_PIN  E23  IOSTANDARD   LVCMOS18 } [get_ports { USRSW0 }]; # USR_DBG_nRST
#set_property -dict { PACKAGE_PIN  Y10  IOSTANDARD   LVCMOS18 } [get_ports { USRSW1 }]; # ???


#set_property -dict { PACKAGE_PIN AK12  IOSTANDARD   LVCMOS33 } [get_ports { CWIO_HS1 }]; 
#set_property -dict { PACKAGE_PIN AL12  IOSTANDARD   LVCMOS33 } [get_ports { CWIO_HS2 }]; 
#set_property -dict { PACKAGE_PIN AL10  IOSTANDARD   LVCMOS33 } [get_ports { CWIO_IO1 }];   # OT_IOB4
#set_property -dict { PACKAGE_PIN AN9   IOSTANDARD   LVCMOS33 } [get_ports { CWIO_IO2 }];   # OT_IOB5
#set_property -dict { PACKAGE_PIN AM10  IOSTANDARD   LVCMOS33 } [get_ports { CWIO_IO3 }];   # OT_IOB6
#set_property -dict { PACKAGE_PIN AM11  IOSTANDARD   LVCMOS33 } [get_ports { CWIO_IO4 }]; 
#set_property -dict { PACKAGE_PIN AN11  IOSTANDARD   LVCMOS33 } [get_ports { CWIO_MISO }];  # OT_IOB11
#set_property -dict { PACKAGE_PIN AN12  IOSTANDARD   LVCMOS33 } [get_ports { CWIO_MOSI }];  # OT_IOB12
#set_property -dict { PACKAGE_PIN  Y20  IOSTANDARD   LVCMOS33 } [get_ports { CWIO_RST }];   # ???
#set_property -dict { PACKAGE_PIN AP13  IOSTANDARD   LVCMOS33 } [get_ports { CWIO_TPDIC }]; # PMOD2_IO7_3V3
#set_property -dict { PACKAGE_PIN AL13  IOSTANDARD   LVCMOS33 } [get_ports { CWIO_TPDID }]; # PMOD2_IO8_3V3
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

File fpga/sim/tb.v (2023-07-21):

/* 
ChipWhisperer Artix Target - Simple testbench to check for signs of life.

Copyright (c) 2020, NewAE Technology Inc.
All rights reserved.

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
THIS SOFTWARE IS PROVIDED BY THE COPYRIGHT HOLDERS AND CONTRIBUTORS "AS IS" AND
ANY EXPRESS OR IMPLIED WARRANTIES, INCLUDING, BUT NOT LIMITED TO, THE IMPLIED
WARRANTIES OF MERCHANTABILITY AND FITNESS FOR A PARTICULAR PURPOSE ARE
DISCLAIMED. IN NO EVENT SHALL THE COPYRIGHT OWNER OR CONTRIBUTORS BE LIABLE FOR
ANY DIRECT, INDIRECT, INCIDENTAL, SPECIAL, EXEMPLARY, OR CONSEQUENTIAL DAMAGES
(INCLUDING, BUT NOT LIMITED TO, PROCUREMENT OF SUBSTITUTE GOODS OR SERVICES;
LOSS OF USE, DATA, OR PROFITS; OR BUSINESS INTERRUPTION) HOWEVER CAUSED AND
ON ANY THEORY OF LIABILITY, WHETHER IN CONTRACT, STRICT LIABILITY, OR TORT
(INCLUDING NEGLIGENCE OR OTHERWISE) ARISING IN ANY WAY OUT OF THE USE OF THIS
SOFTWARE, EVEN IF ADVISED OF THE POSSIBILITY OF SUCH DAMAGE.

The views and conclusions contained in the software and documentation are those
of the authors and should not be interpreted as representing official policies,
either expressed or implied, of NewAE Technology Inc.
*/

`timescale 1ns / 1ns
`default_nettype none 

`include "cw341_defines.v"

module tb();
    parameter pBYTECNT_SIZE = 7;
    parameter pADDR_WIDTH = 8;
    parameter pUSB_CLOCK_PERIOD = 10;
    parameter pPLL_CLOCK_PERIOD = 6;
    parameter pSEED = 1;
    parameter pTIMEOUT = 30000;
    parameter pVERBOSE = 0;
    parameter pDUMP = 0;

    reg usb_clk;
    reg usb_clk_enable;
    wire [7:0] usb_data;
    reg [7:0] usb_wdata;
    reg [7:0] usb_addr;
    reg usb_rdn;
    reg usb_wrn;
    reg usb_cen;
    reg usb_alen;
    reg usb_trigger;

    reg pushbutton;
    reg pll_clk1;
    wire tio_clkin;
    wire trig_out;

    wire [7:0] led;
    wire [7:0] usrdip;

    wire tio_trigger;
    wire tio_clkout;


    int seed;
    int errors;
    int warnings;
    int i;
    
    reg [31:0] write_data;

    wire clk = pll_clk1;  // shorthand for testbench

   int cycle;
   int total_time;

   reg [127:0] read_data;
   reg [127:0] expected_cipher = 128'h8a278bf8fa2812bc39e52c76205af377;

   localparam pSTREAM = 0;
   localparam pADC_LOW_RES = 0;
   localparam pSLOW_READS = 0; // TODO?

   initial begin
      seed = pSEED;
      errors = 0;
      warnings = 0;
      $display("Running with seed=%0d", seed);
      $urandom(seed);
      if (pDUMP) begin
         $dumpfile("results/tb.fst");
         $dumpvars(0, tb);
      end
      usb_clk = 1'b1;
      usb_clk_enable = 1'b1;
      pll_clk1 = 1'b1;

      usb_wdata = 0;
      usb_addr = 0;
      usb_rdn = 1;
      usb_wrn = 1;
      usb_cen = 1;
      usb_alen = 1;
      usb_trigger = 0;

      pushbutton = 1;
      pll_clk1 = 0;

      #(pUSB_CLOCK_PERIOD*2) pushbutton = 0;
      #(pUSB_CLOCK_PERIOD*2) pushbutton = 1;
      #(pUSB_CLOCK_PERIOD*10);

      write_byte(`REG_SRAM_MEM_BYTES, 32);
      write_byte(`REG_SRAM_EN, 1);

      write_bytes(4, `REG_LB_STOP_ADDR, 32'h3);
      write_byte(`REG_LB_MANUAL, 8);
      //repeat (50) @(posedge usb_clk);
      //write_byte(`REG_LB_MANUAL, 1);
      //repeat (10) @(posedge usb_clk);
      //write_byte(`REG_LB_MANUAL, 0);

      write_bytes(16, `REG_CRYPT_TEXTIN, {32'h12345678, 32'habcdef01, 32'h87654321, 32'hdeadbeef});
      write_bytes(16, `REG_CRYPT_KEY, {32'habcdef01, 32'h12345678, 32'hdeadbeef, 32'h87654321});

      $display("Encrypting via register...");
      write_byte(`REG_CRYPT_GO, 1);
      repeat (5) @(posedge usb_clk);
      wait_done();
      read_bytes(16, `REG_CRYPT_CIPHEROUT, read_data);
      if (read_data == expected_cipher) begin
         $display("Good result");
      end
      else begin
         errors += 1;
         $display("ERROR: expected %h", expected_cipher);
         $display("            got %h", read_data);
      end


      /*
      $display("Encrypting via usb_trigger (USB clock disabled)...");
      write_bytes(1, `REG_CRYPT_TEXTIN, 8'h01);
      expected_cipher = 128'h0efee0bff4cf170752994fb45bd45934;
      repeat (5) @(posedge usb_clk);
      usb_clk_enable = 1'b0;
      @(posedge usb_clk) usb_trigger = 1'b1;
      repeat (10) @(posedge usb_clk); 
      usb_trigger = 1'b0;
      repeat (30) @(posedge pll_clk1);
      usb_clk_enable = 1'b1;
      repeat (5) @(posedge usb_clk);
      wait_done();
      read_bytes(16, `REG_CRYPT_CIPHEROUT, read_data);
      if (read_data == expected_cipher) begin
         $display("Good result");
      end
      else begin
         errors += 1;
         $display("ERROR: expected %h", expected_cipher);
         $display("            got %h", read_data);
      end


      $display("Encrypting via usb_trigger (USB clock enabled)...");
      write_bytes(1, `REG_CRYPT_TEXTIN, 8'h02);
      expected_cipher = 128'h8623e205b50bede46f795d1aad15faae;
      @(posedge usb_clk) usb_trigger = 1'b1;
      repeat (10) @(posedge usb_clk); 
      usb_trigger = 1'b0;
      repeat (30) @(posedge pll_clk1);
      repeat (5) @(posedge usb_clk);
      wait_done();
      read_bytes(16, `REG_CRYPT_CIPHEROUT, read_data);
      if (read_data == expected_cipher) begin
         $display("Good result");
      end
      else begin
         errors += 1;
         $display("ERROR: expected %h", expected_cipher);
         $display("            got %h", read_data);
      end

      $display("Encrypting via usb_trigger (USB clock disabled, returns mid-encryption)...");
      write_bytes(1, `REG_CRYPT_TEXTIN, 8'h03);
      expected_cipher = 128'h46be87df4d18bfe6d0d1d3b20b6bf382;
      repeat (5) @(posedge usb_clk);
      usb_clk_enable = 1'b0;
      @(posedge usb_clk) usb_trigger = 1'b1;
      repeat (2) @(posedge usb_clk); 
      usb_trigger = 1'b0;
      repeat (2) @(posedge pll_clk1);
      usb_clk_enable = 1'b1;
      repeat (1) @(posedge usb_clk);
      wait_done();
      read_bytes(16, `REG_CRYPT_CIPHEROUT, read_data);
      if (read_data == expected_cipher) begin
         $display("Good result");
      end
      else begin
         errors += 1;
         $display("ERROR: expected %h", expected_cipher);
         $display("            got %h", read_data);
      end
      */


      $display("done!");
      #(pUSB_CLOCK_PERIOD*10);
      if (errors)
         $display("SIMULATION FAILED (%0d errors, %0d warnings).", errors, warnings);
      else
         $display("Simulation passed (%0d warnings).", warnings);
      $finish;

   end

   // maintain a cycle counter
   always @(posedge clk) begin
      if (pushbutton == 0)
         cycle <= 0;
      else
         cycle <= cycle + 1;
   end


   // timeout thread:
   initial begin
      #(pUSB_CLOCK_PERIOD*pTIMEOUT);
      errors += 1;
      $display("ERROR: global timeout");
      $display("SIMULATION FAILED (%0d errors).", errors);
      $finish;
   end


   reg read_select = 1'b0;
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

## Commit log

2023-03-21 Add schematic
2023-03-24 Update schematic for cw341
2023-06-15 Add 04 schematic
2023-07-20 Adding some stub files
    [CW330_NewKintexFPGA.PrjPcb, CW340_Block_Diagram.SchDoc, CW340_Clocks.SchDoc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]
2023-07-20 Add board photo
2023-07-20 Fix board index?
2023-07-20 Update schematic, fix image maybe
2023-07-20 Add schematic ref
2023-07-20 Add kintex US schematic
2023-08-17 Move ALE pin to more convenient location.
    Can now use a ribbon cable from J23 to J24.
2024-07-02 Add additional USB UART information
2024-07-03 Update FTDI driver Linux info
2026-02-26 Add latest board PDFs
